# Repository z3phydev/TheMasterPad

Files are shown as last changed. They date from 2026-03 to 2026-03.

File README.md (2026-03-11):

# TheMasterPad
## What is this thing?
Well it is USB Hub that has 5 USB A ports and a USB C port... **But** it has 8 MX switches which are Programable Buttons aswell as a Rotary Encoder all of which are powered by a Seeed XIAO RP2040

## How to use
1) Assemble
2) Flash CircutPython to the XIAO (or QMK, if you do skip step 3 and 4, and if you are flashing QMK you know what you are doing anyway)
3) Download the adafruit hid lib and put it into the lib folder
4) Upload the code (which you can edit to your liking)
5) Enjoy
## Why did I make it?
I made this project because to my knowledge it hasn't been made. Even though it hasn't I still think its a good combo. It is also an intrusive thought after looking at keyboards.
## Repo Guide
- In the Folder 3D you will find the step and wrl (Kicad 3D file) files, the step is in a zip cause github said its to big and the keycaps wouldn't export so thats in ther aswell :)
- In the Kicad Folder you will find the PCB and Schematic files awell as a sub-folder containing custom footprints
- In the Firmware folder you'll find the code
- In the Production Folder you will find 3 files needed for JLC, gerbers, A BOM and Pick and Place file for assembly
- BOM.csv is the whole project cost basically. It also contains all the parts for building

## 3D Model

## PCB



## Schematic



## BOM

|Reference(s)|Qty |Value/Description |MFR |MFR No. |Unit Price GBP|Total Price GBP|Link |FIELD9 |FIELD10 |FIELD11 |
|---|---|---|---|---|---|---|---|---|---|---|
|~ |5 (2 assebeled)|PCB and Partial assebly |JLCPCB |~ |~ |23.62 |https://jlcpcb.com/ | | | |
|U3 |1 |Seeed XIAO RP2040 with Headers|Raspberry Pi|102010428 |4.8 |4.8 |https://thepihut.com/products/seeed-xiao-rp2040 | | | |
|SW2-9 |8 |Cherry Mx Brown Swtich |CHERRY |MX1A-G1NW |0.48 |4.32 |https://www.keyboardco.com/product/cherry-key-switch-module-brown-tactile-pcb-mount.asp | | | |
|SW1 |1 |Rotary Encoder |Bourns |PEC11R-4325F-S0012|1.87 |1.87 |https://uk.rs-online.com/web/p/mechanical-rotary-encoders/7377767 | | | |
|~ |8 |Keycaps In Various Colours |JYTECH |JYT--1657 |0.15 |1.2 |https://www.alibaba.com/product-detail/Multi-color-XDA-Blank-Keycap-1_1601173995121.html| | | |
|J2-6 |5 |USB A Port |Molex |67643-2911 |1.78 |8.87 |https://uk.rs-online.com/web/p/usb-connectors/9048200 | | | |
| | | | | | | | | | | |
| | | | | | | | | |Total Price USD approx|Total Price GBP|
| | | | | | | | |Items |60.18 |44.84 |
| | | | | | | | |Shipping (and fees)|31.05 |23.14 |
| | | | | | | | |Final |91.2 |67.98 |

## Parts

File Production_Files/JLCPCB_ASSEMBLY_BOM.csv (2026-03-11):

Comment | Designator | Footprint | JLCPCB Part
CH334R | U1, U2 | QSOP-16_3.9x4.9mm_P0.635mm | C4154405
USB C Port | J7, J8 | USB_C_Receptacle_Molex_105450-0101 | C134092
100nF Cap | C4 | 603 | C14663
1uF Cap | C1, C2 | 603 | C15849
10uF Cap | C3 | 603 | C19702
5.1kOhm Resistor | R1, R2, R3, R4 | 805 | C27834
220uF Cap | C5, C6, C7, C8, C9, C10 | D6.3xL8mm | C94440

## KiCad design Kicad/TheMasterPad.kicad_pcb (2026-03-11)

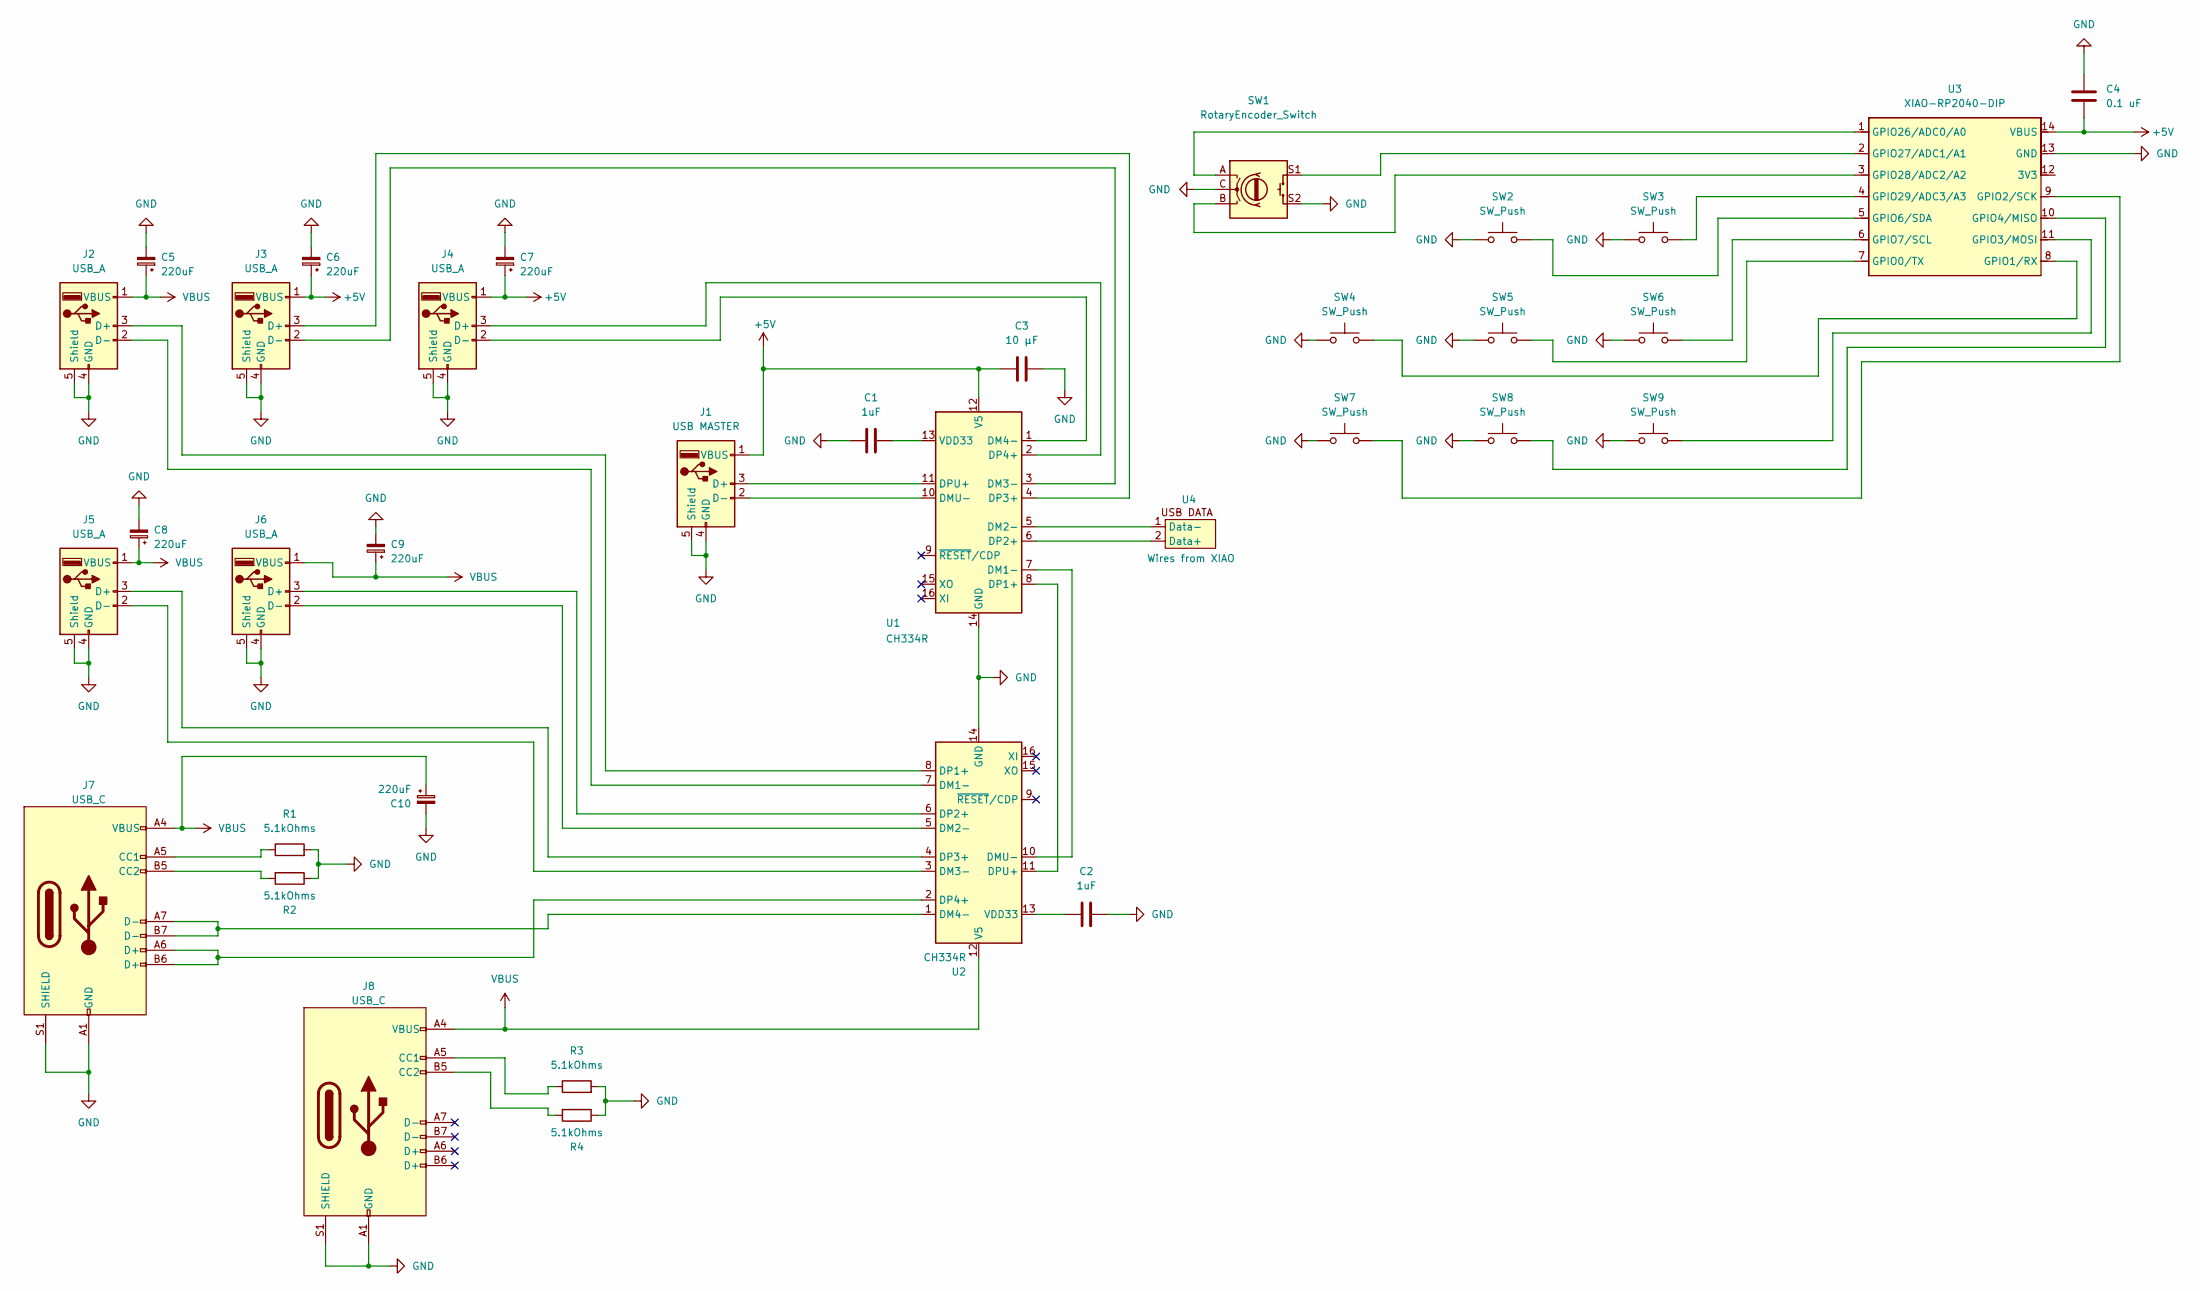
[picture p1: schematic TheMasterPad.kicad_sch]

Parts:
C1, C2: 1uF; C_0603_1608Metric
C3: 10 µF; C_0603_1608Metric
C4: 0.1 uF; C_0603_1608Metric
C5, C6, C7, C8, C9, C10: 220uF; C_Radial_D6.3mm_H7.0mm_P2.50mm
J1: USB MASTER; 4pinhole
J2, J3, J4, J5, J6: USB_A; USB_A_Molex_67643_Horizontal
J7, J8: USB_C; USB_C_Receptacle_Molex_105450-0101
R1, R2, R3, R4: 5.1kOhms; R_0805_2012Metric
SW1: RotaryEncoder_Switch; RotaryEncoder_Alps_EC12E-Switch_Vertical_H20mm_CircularMoun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
SW2, SW3, SW4, SW5, SW6, SW7, SW8, SW9: SW_Push; SW_Cherry_MX_1.00u_PCB
U1, U2: CH334R; QSOP-16_3.9x4.9mm_P0.635mm
U3: XIAO-RP2040-DIP
U4: Wires from XIAO; 2pinhole

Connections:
+5V: C3.1, C4.1, C6.1, C7.1, J1.1 (VBUS), J3.1 (VBUS), J4.1 (VBUS), U1.12 (V5), U3.14 (VBUS)
GND: C1.2, C2.1, C3.2, C4.2, C5.2, C6.2, C7.2, C8.2, C9.2, C10.2, J1.4 (GND), J1.5 (Shield), J2.4 (GND), J2.5 (Shield), J3.4 (GND), J3.5 (Shield), J4.4 (GND), J4.5 (Shield), J5.4 (GND), J5.5 (Shield), J6.4 (GND), J6.5 (Shield), J7.A1 (GND), J7.A12 (GND), J7.B1 (GND), J7.B12 (GND), J7.S1 (SHIELD), J8.A1 (GND), J8.A12 (GND), J8.B1 (GND), J8.B12 (GND), J8.S1 (SHIELD), R1.2, R2.1, R3.2, R4.1, SW1.C, SW1.S2, SW2.1, SW3.1, SW4.1, SW5.1, SW6.1, SW7.1, SW8.1, SW9.1, U1.14 (GND), U2.14 (GND), U3.13 (GND)
unnamed: J1.3 (D+), U1.11 (DPU+)
unnamed: J1.2 (D-), U1.10 (DMU-)
unnamed: J2.3 (D+), U2.8 (DP1+)
unnamed: J2.2 (D-), U2.7 (DM1-)
unnamed: J3.3 (D+), U1.4 (DP3+)
unnamed: J3.2 (D-), U1.3 (DM3-)
unnamed: J4.3 (D+), U1.2 (DP4+)
unnamed: J4.2 (D-), U1.1 (DM4-)
unnamed: J5.3 (D+), U2.4 (DP3+)
unnamed: J5.2 (D-), U2.3 (DM3-)
unnamed: J6.3 (D+), U2.6 (DP2+)
unnamed: J6.2 (D-), U2.5 (DM2-)
unnamed: J7.A5 (CC1), R1.1
unnamed: J7.B5 (CC2), R2.2
unnamed: J8.A5 (CC1), R3.1
unnamed: J8.B5 (CC2), R4.2
unnamed: U1.7 (DM1-), U2.10 (DMU-)
unnamed: U1.5 (DM2-), U4.1 (Data-)
unnamed: U1.8 (DP1+), U2.11 (DPU+)
unnamed: U1.6 (DP2+), U4.2 (Data+)
unnamed: C1.1, U1.13 (VDD33)
unnamed: J7.A7 (D-), J7.B7 (D-), U2.1 (DM4-)
unnamed: J7.A6 (D+), J7.B6 (D+), U2.2 (DP4+)
unnamed: C2.2, U2.13 (VDD33)
unnamed: SW5.2, U3.7 (GPIO0/TX)
unnamed: SW4.2, U3.8 (GPIO1/RX)
unnamed: SW7.2, U3.9 (GPIO2/SCK)
unnamed: SW9.2, U3.11 (GPIO3/MOSI)
unnamed: SW8.2, U3.10 (GPIO4/MISO)
unnamed: SW2.2, U3.5 (GPIO6/SDA)
unnamed: SW6.2, U3.6 (GPIO7/SCL)
unnamed: SW1.A, U3.1 (GPIO26/ADC0/A0)
unnamed: SW1.S1, U3.2 (GPIO27/ADC1/A1)
unnamed: SW1.B, U3.3 (GPIO28/ADC2/A2)
unnamed: SW3.2, U3.4 (GPIO29/ADC3/A3)
VBUS: C5.1, C8.1, C9.1, C10.1, J2.1 (VBUS), J5.1 (VBUS), J6.1 (VBUS), J7.A4 (VBUS), J7.A9 (VBUS), J7.B4 (VBUS), J7.B9 (VBUS), J8.A4 (VBUS), J8.A9 (VBUS), J8.B4 (VBUS), J8.B9 (VBUS), U2.12 (V5)

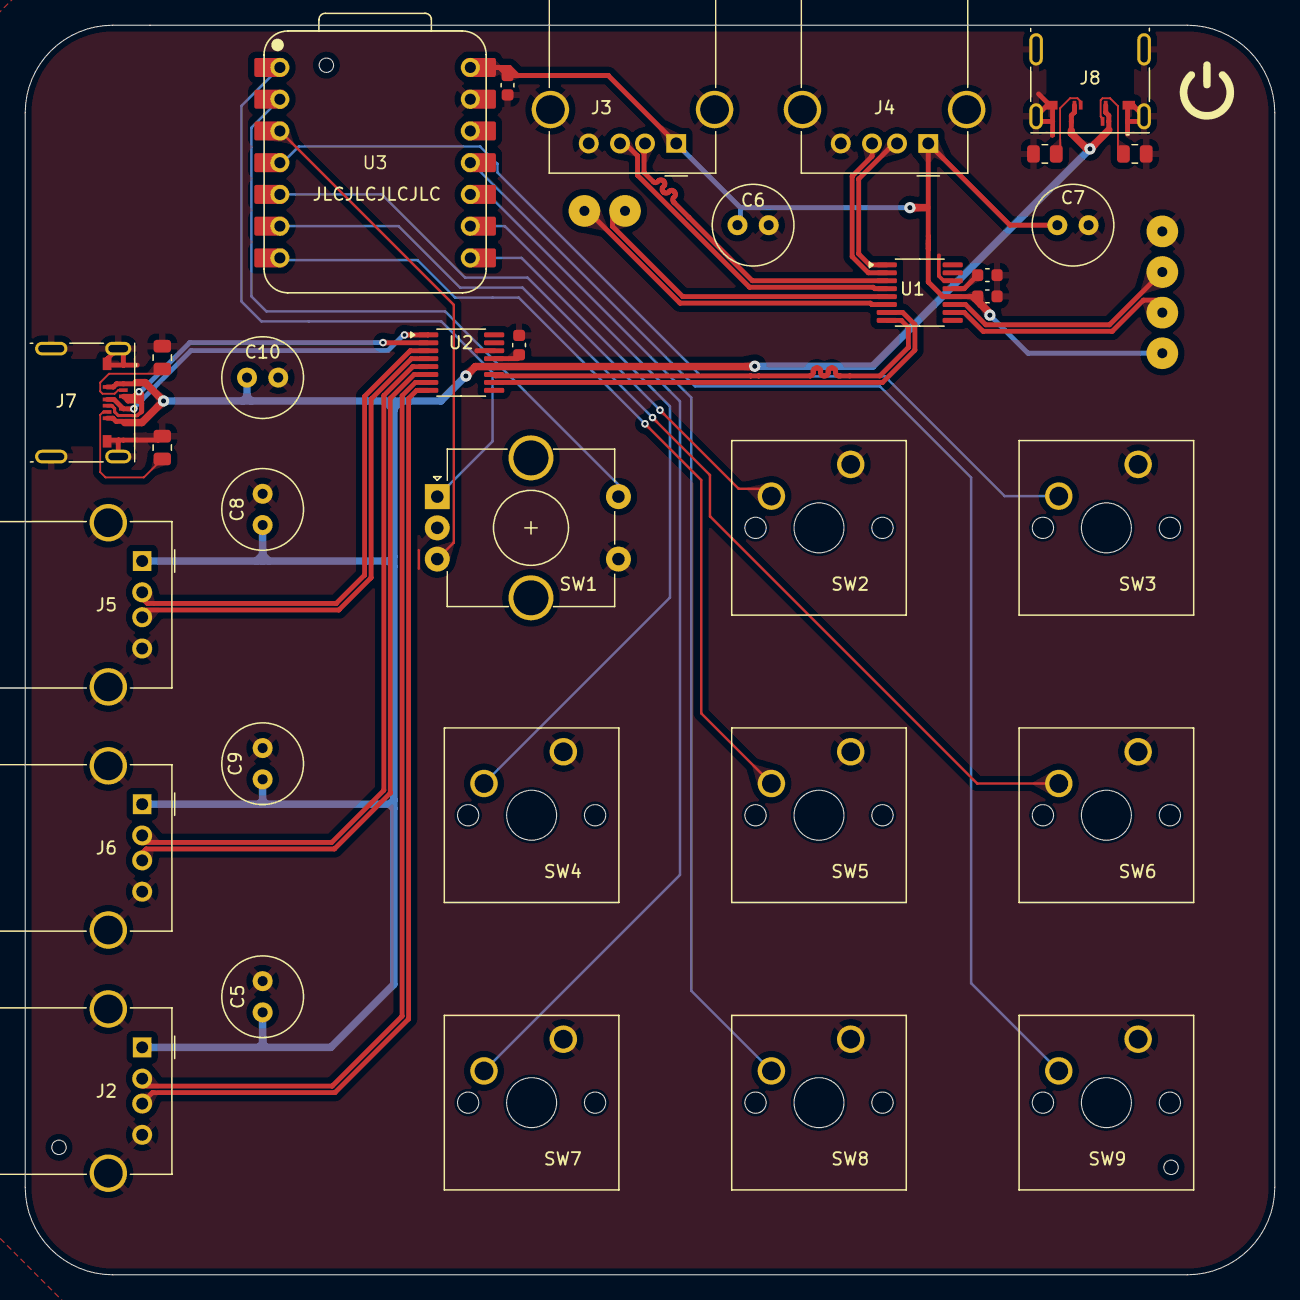
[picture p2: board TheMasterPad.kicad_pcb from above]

Board: 2 copper layers, 100.0 x 100.0 mm, 35 parts (0 on the bottom side), 38 nets.

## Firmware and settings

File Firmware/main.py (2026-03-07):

import board
import digitalio
import usb_hid
import rotaryio
import time

from adafruit_hid.keyboard import Keyboard
from adafruit_hid.keycode import Keycode
from adafruit_hid.consumer_control import ConsumerControl
from adafruit_hid.consumer_control_code import ConsumerControlCode

keyboard = Keyboard(usb_hid.devices)
consumer = ConsumerControl(usb_hid.devices)
encoder = rotaryio.IncrementalEncoder(board.GP26, board.GP28)
last_position = encoder.position
encoder_button = digitalio.DigitalInOut(board.GP27)
encoder_button.direction = digitalio.Direction.INPUT
encoder_button.pull = digitalio.Pull.UP

macro_pins = [
    board.GP0, board.GP1, board.GP2, board.GP3
    board.GP4, board.GP6, board.GP7, board.GP29
]

buttons = []

for pin in macro_pins:
    btn = digitalio.DigitalInOut(pin)
    btn.direction = digitalio.Direction.INPUT
    btn.pull = digitalio.Pull.UP
    buttons.append(btn)

last_button_states = [True] * len(buttons)
last_encoder_button = True

While True:
    position = encoder.position

    if position > last_position:
        consumer.send(ConsumerControlCode.VOLUME_INCREMENT)
    elif position < last_position:
        consumer.send(ConsumerControlCode.VOLUME_DECREMENT)

    last_position = position

    if not encoder_button.value and last_encoder_button:
        consumer.send(ConsumerControlCode.MUTE)
        time.sleep(0.2)

    last_encoder_button = encoder_button.value

    for i, button in enumerate(buttons):
        if not button.value and last_button_states[i]:
            # Macros
            if i == 0:
                keyboard.send(Keycode.CONTROL, Keycode.C)   # Copy
            elif i == 1:
                keyboard.send(Keycode.CONTROL, Keycode.V)   # Paste
            elif i == 2:
                keyboard.send(Keycode.CONTROL, Keycode.Z)   # Undo
            elif i == 3:
                keyboard.send(Keycode.CONTROL, Keycode.S)   # Save
            elif i == 4:
                keyboard.send(Keycode.ALT, Keycode.TAB)     # App switch
            elif i == 5:
                keyboard.send(Keycode.GUI, Keycode.D)       # Show desktop
            elif i == 6:
                keyboard.send(Keycode.CONTROL, Keycode.SHIFT, Keycode.ESC)  # Task manager
            elif i == 7:
                keyboard.send(Keycode.F5)                   # Refresh or Run depending on the app

            time.sleep(0.2)

        last_button_states[i] = button.value

    time.sleep(0.01)

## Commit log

2026-02-24 Add schematic section to README
2026-02-24 Add BOM section with components and pricing
    Added detailed BOM with components, quantities, and links.
2026-02-24 Implement rotary encoder and macro buttons functionality
2026-02-25 Update README
    Added a sub-folder note for custom footprints in Kicad.
2026-02-25 Implement rotary encoder and macro buttons for control
2026-02-25 Clarify folder contents and assembly instructions
    Updated README to clarify folder contents and assembly files.
2026-03-07 Update encoder and button GPIO pins in main.py
2026-03-07 Change microcontroller from Pi Pico to Seeed XIAO RP2040
    Updated the microcontroller reference from Pi Pico to Seeed XIAO RP2040.
2026-03-10 Update JLCPCB assembly BOM with new component
    Added missing component C3 to the assembly BOM.
    [JLCPCB_ASSEMBLY_BOM.csv]
2026-03-10 Revise BOM with updated components and prices
    Updated BOM section with new components and pricing.
2026-03-10 Correct device name and update images in README
    Updated instructions to reflect the correct device name and added new images for PCB and schematic.
2026-03-10 Add images to README for 3D model and PCB
    Added images for 3D model and PCB sections.
2026-03-11 Remove duplicate entries in TheMasterPad-pos.csv
    [TheMasterPad-pos.csv]
2026-03-11 Update images and BOM table in README
2026-03-11 Add BOM table with components and pricing details
